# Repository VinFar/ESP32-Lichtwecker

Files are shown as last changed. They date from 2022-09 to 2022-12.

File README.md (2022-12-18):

ESP32 Lichtwäcker
===
# Introduction
This repository is about a custom built alarm clock, which wakes you up with light instead of sound. It mimics the sunrise inside your bedroom, so that you are been woken up gently and more natural. The main light source (a.k.a. wake light) is a high power LED with around 50W of power. This is plenty of power to illuminate a big room.

It features a convient Web Interface, where you configure the alarm clock.
You can set the alarm time, the rising time, the maximum LED power and much more.
When a alarm sets in, the brightness is slowly increased (configurable) until the maximum power (configurable) is reached. Then the brightness is held at this point for specific amount of time (configurable).

With the integrated button it is possible to switch off the alarm, activate a "reading light" (low brightness), activate full power or activate the last use RGB Effect.

Beside the high power LED there are 24 WS2812B RGB LED chips arranged in a circle. This makes it possible to use the alarm clock also as a mood or RGB light. It features a lot of effects, that can be selected over the Web Interface.

# Features
The alarm clock has the following features:

- **50W high power LED**
- **High efficient LED driver**
- **ESP32 to control everythin**
- **Custom PCB which implements the electronics**
- **RGB LEDs to create beautiful animations and mood lights**
- **Web Interface to configure the following settings**
  - **Alarm time for each day of the week**
  - **Brightness rising and holding time**
  - **LED power for the wake light**
  - **RGB effect for the mood light**
- **OTA Updates**
- **Alexa and Google Assistant ready ("Alexa, set the alarm light to 20%")**
- **Temperature sensor for the high power LED**
- **Aluminium heat sink with a 30mm fan for cooling**
  - **Fan can switched off, as it obviously makes noise, which is not necessarily desirable when you wake up :)**
- **All parts (beside LED heatsink) are 3D-printable**

## Main LED
___
The mainlight source is a high quality power LED from CREE (CMT2850). It features a CRI of 92, a natural color of 5000K and around 50W of power. It is mounted to the heatsink.
It is driven by an LCM-60 CC-Source from Meanwell. This LED driver has a maximum power output of 60W and can drive a current of max. 1400mA.
For dimming the LED a PWM signal from the ESP32 is used. It is coupled to via an opto-coupler, to prevent GND shifts and other interferences.

## ESP32
___
The alarm clock is powered and controlled over a ESP32. It is mounted on the PCB.

## Other features
___
### Temperature sensor
A LM335 temperature sensor is fixed to the bottom of the heatsink to measure the temperature of the of the main LED. The LM335 outputs an analog voltage which is then measured by an ADC. This method was used over a classic digital OneWire sensor, as the I²C Library is immune to context switches of FreeRTOS. Also, id prevents using a fake DS18B20, as these are very common on AliExpress, eBay etc.

### Fan & heat managment
To enable better cooling of the alarm clock a 30mm fan is used. It is controlled a PWM single, to reduce noise when the temperature is not too hot. In addition, it can completely switched off over the Web Interface.
In both cases a heat managment controls the power of the LED and the fan. The power of the LED is continously reduced, if the the temperature is higher than 70°C.
Thus, the fan can be switched off, resulting in a lower brightness of the LED.

### 

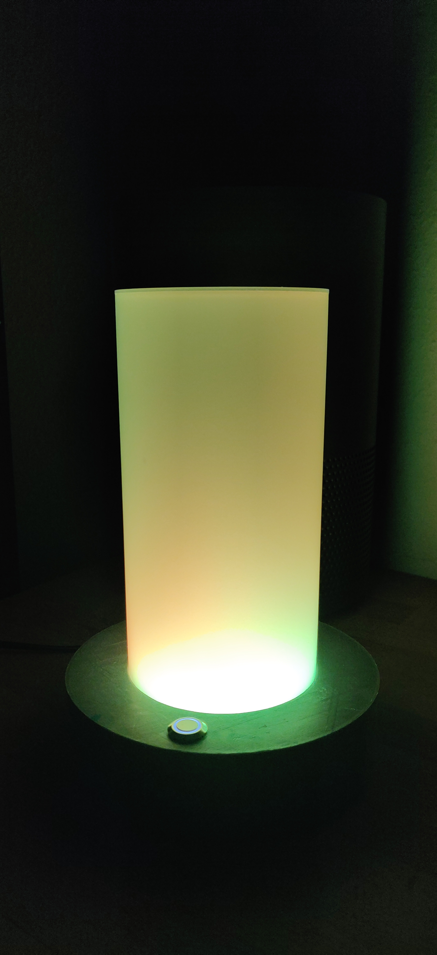
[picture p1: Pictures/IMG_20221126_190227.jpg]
[](image.png)
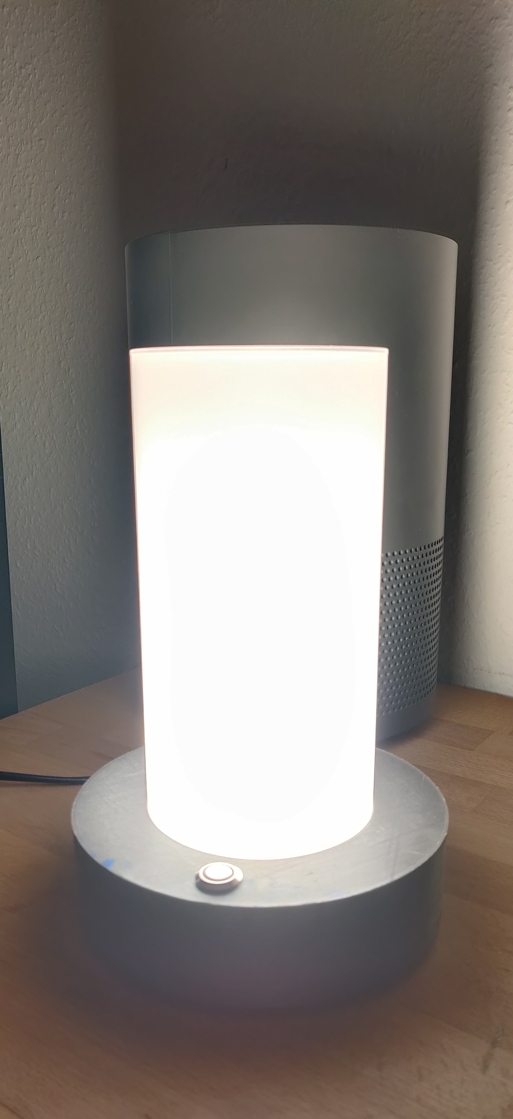
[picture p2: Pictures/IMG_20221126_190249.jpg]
[](image.png)

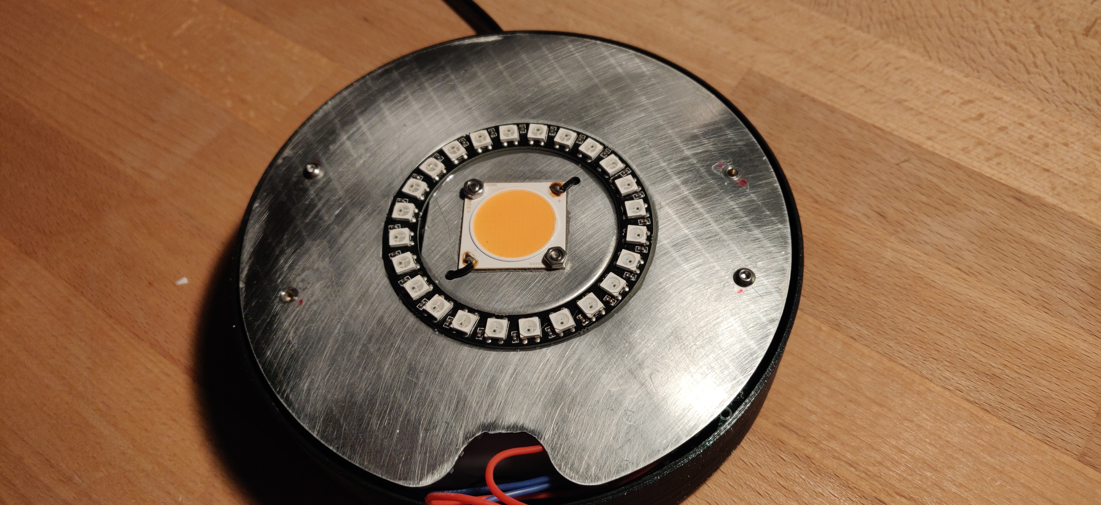
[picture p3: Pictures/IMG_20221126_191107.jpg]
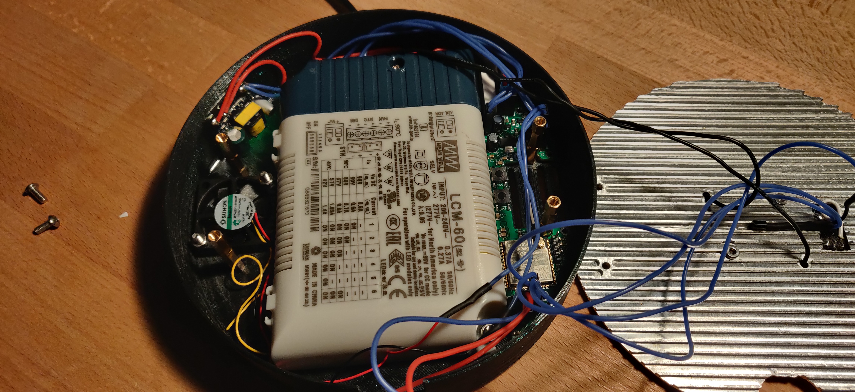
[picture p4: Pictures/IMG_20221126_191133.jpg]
[](image.png)[](image.png)

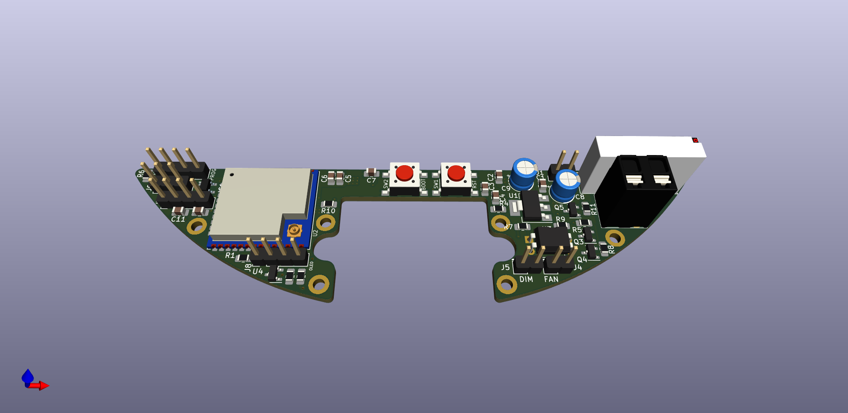
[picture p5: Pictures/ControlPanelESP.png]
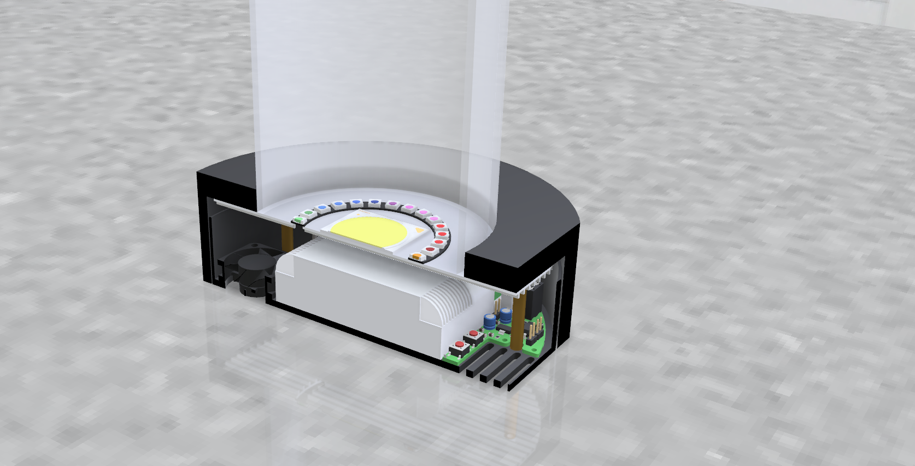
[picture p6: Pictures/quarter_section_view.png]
[](image.png)[](image.png)

### Hardware

### Firmware

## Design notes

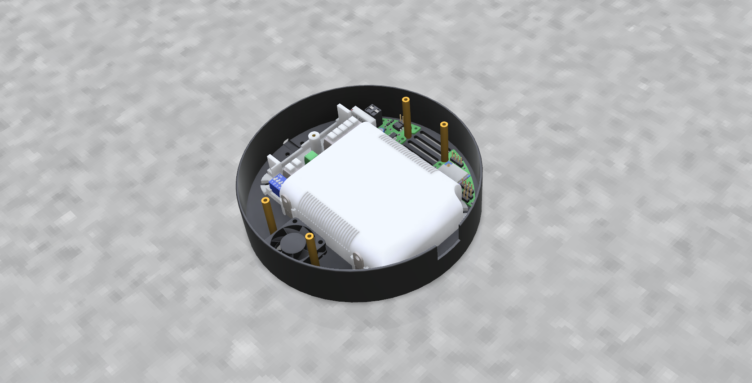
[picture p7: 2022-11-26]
Pictures/electronics1.png

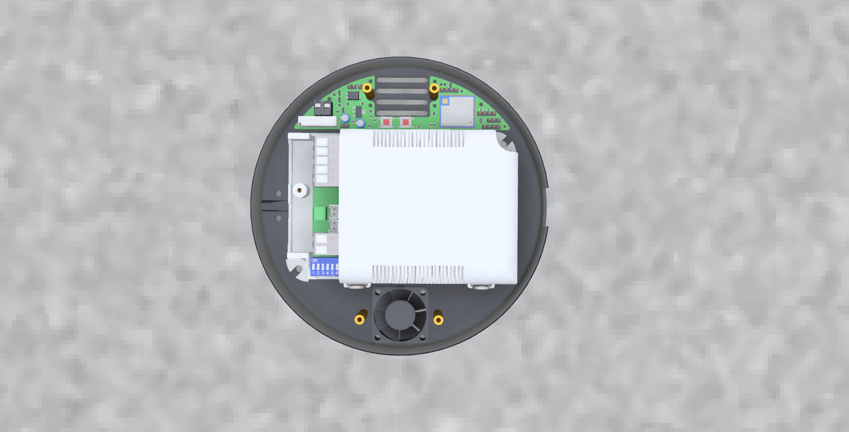
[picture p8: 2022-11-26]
Pictures/electronics2.png

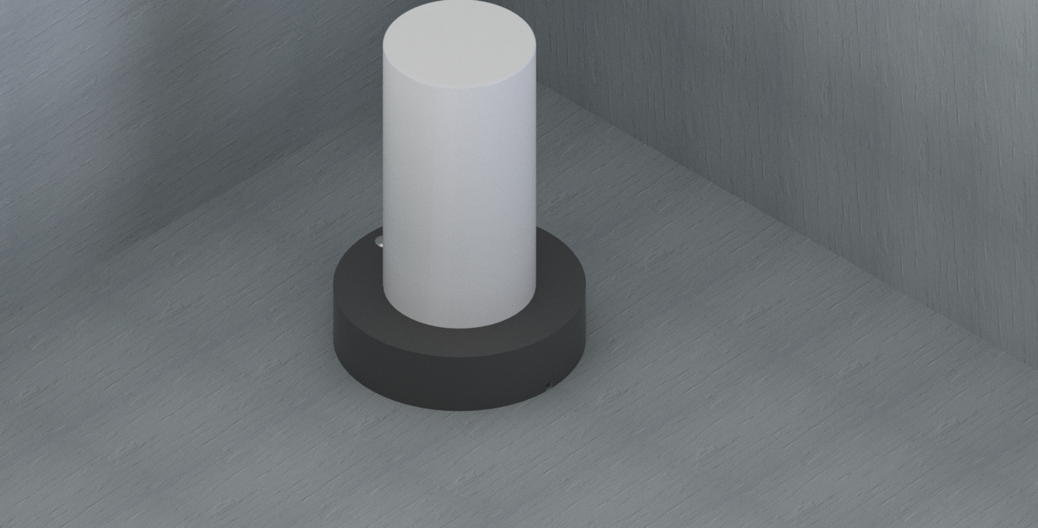
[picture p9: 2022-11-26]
Pictures/assembyl_fuß.png

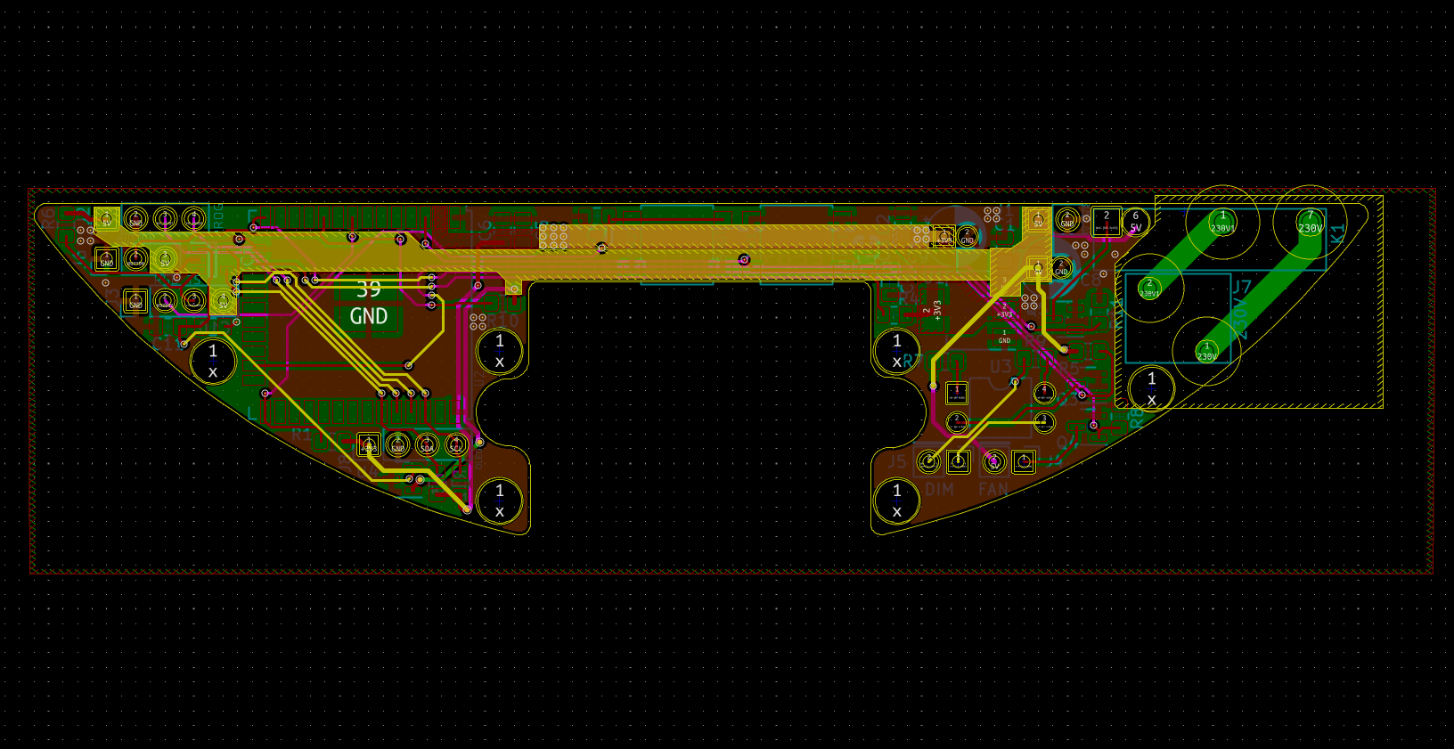
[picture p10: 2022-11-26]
Pictures/Layout.png

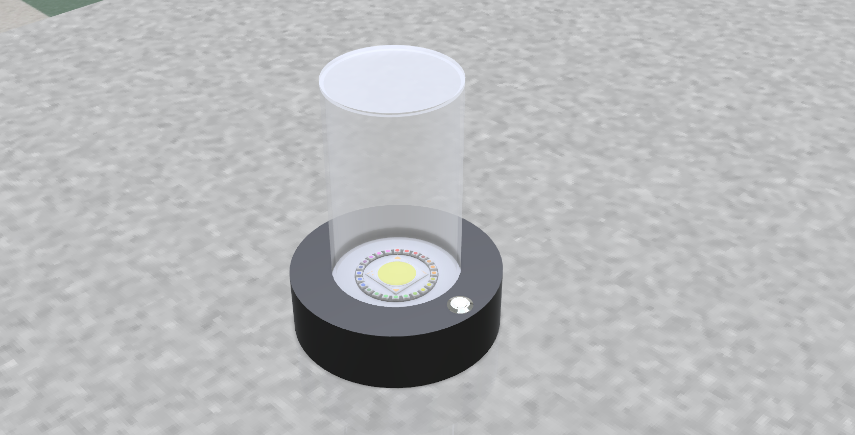
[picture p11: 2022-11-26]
Pictures/assemlbed.png

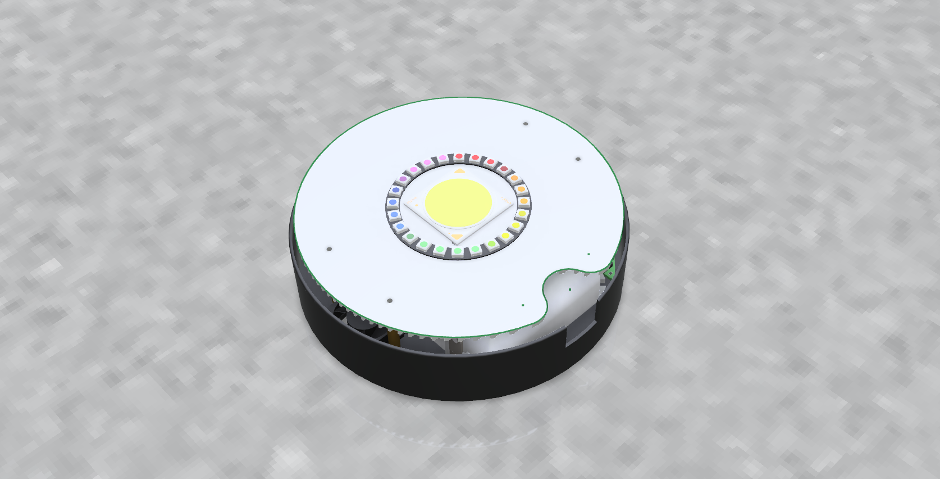
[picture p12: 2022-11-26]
Pictures/aluminium_plate.png

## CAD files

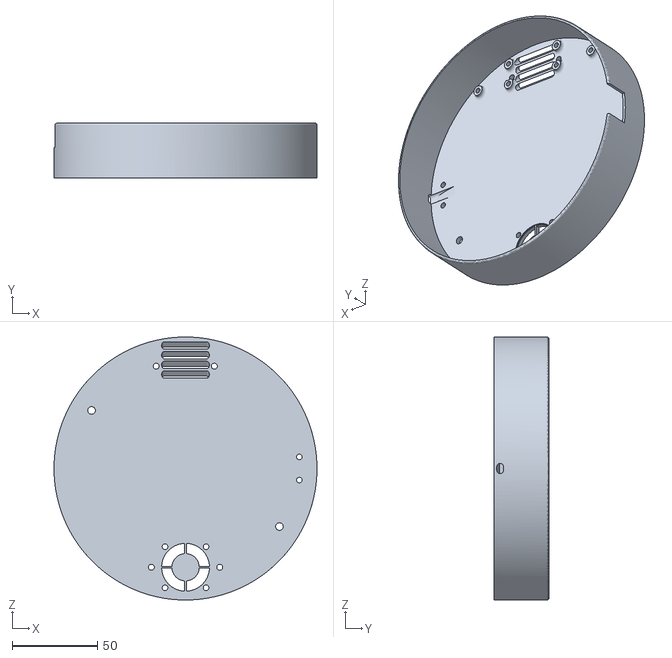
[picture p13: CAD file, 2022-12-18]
3D-Models/Schale.stl
154.0 x 32.0 x 154.0

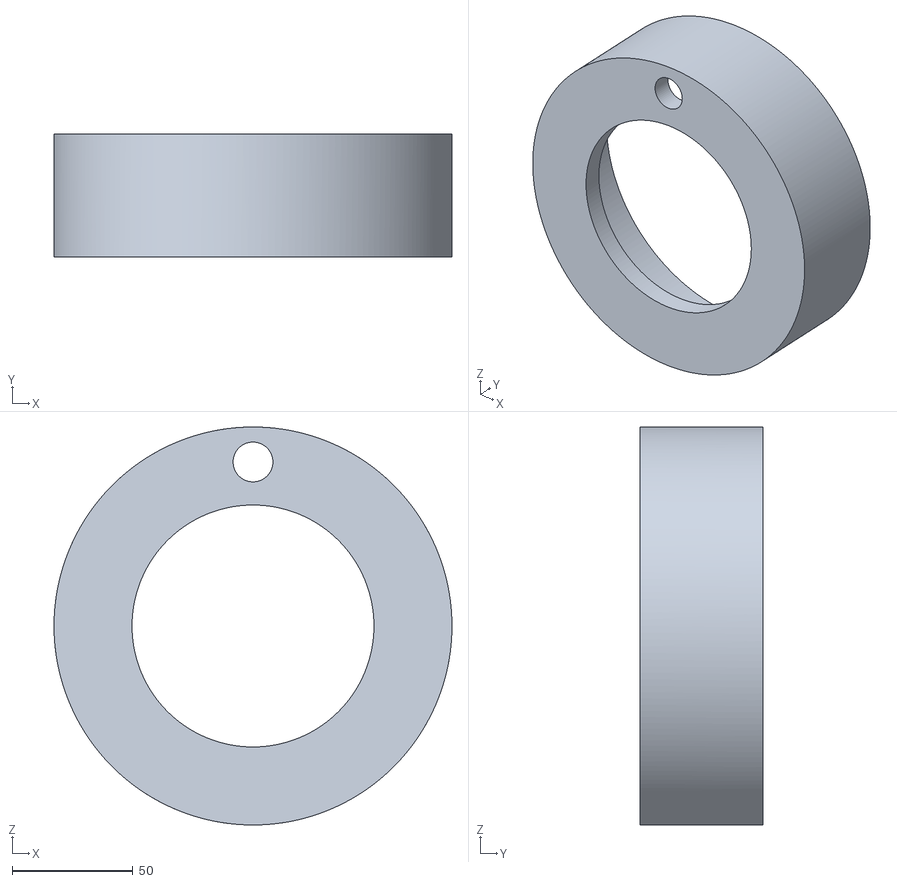
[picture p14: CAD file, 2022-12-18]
3D-Models/Oberteil.stl
165.0 x 51.0 x 165.0

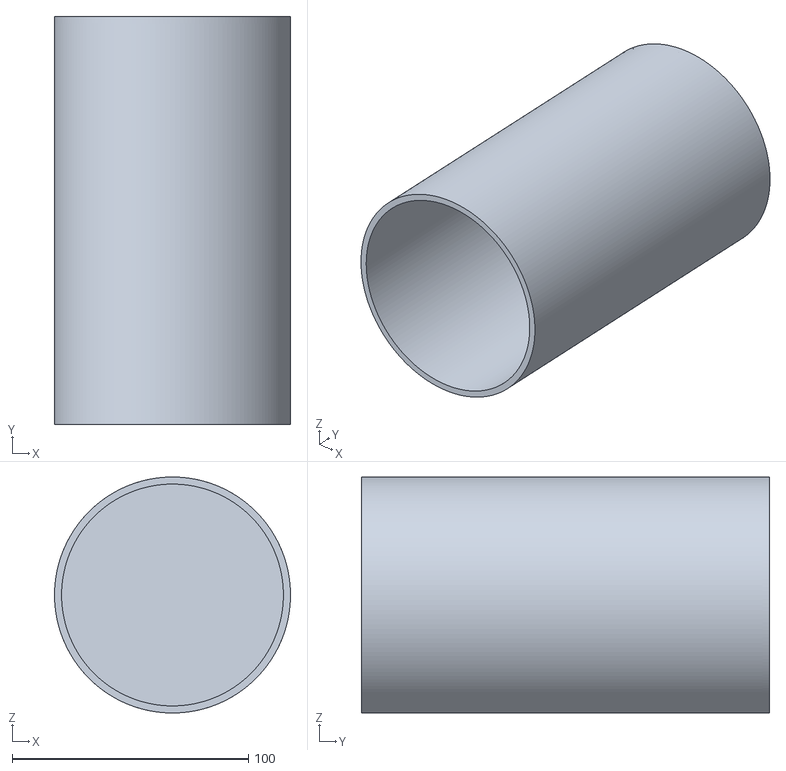
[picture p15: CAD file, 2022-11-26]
3D-Models/Plexiglas.stl
100.0 x 173.0 x 100.0

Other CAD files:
KiCad/ControlPanelESP/ControlPanelESP.iam
KiCad/ControlPanelESP/HF49FDxxx-1Hx2x.iam
KiCad/ControlPanelESP/SOLID.ipt

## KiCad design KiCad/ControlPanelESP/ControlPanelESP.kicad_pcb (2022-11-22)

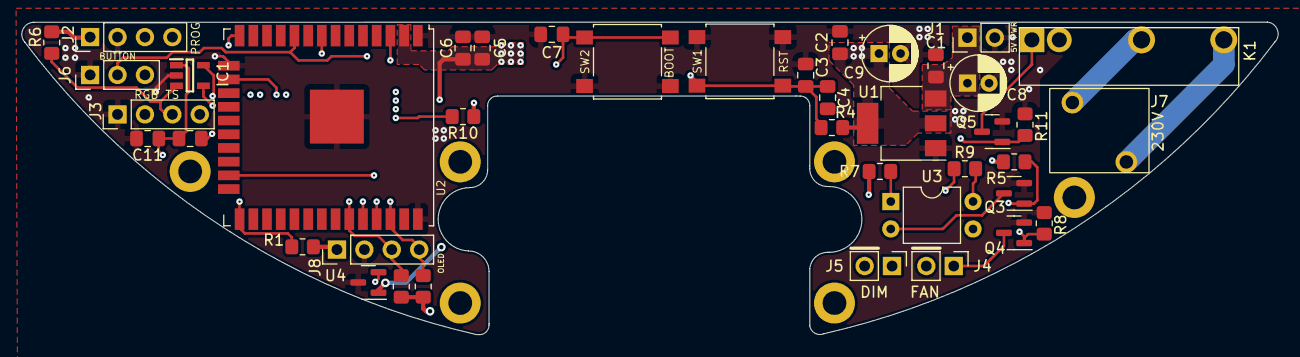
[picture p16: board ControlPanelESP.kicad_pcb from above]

Board: 4 copper layers, 116.4 x 29.0 mm, 47 parts (0 on the bottom side), 25 nets.

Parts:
C1, C2, C5: 22u; C_0805_2012Metric_Pad1.18x1.45mm_HandSolder
C3, C4, C6, C7, C11: 100n; C_0805_2012Metric_Pad1.18x1.45mm_HandSolder
C8, C9: C_Polarized; CP_Radial_D5.0mm_P2.00mm
C10: 10u; C_0805_2012Metric_Pad1.18x1.45mm_HandSolder
H1, H2, H3, H4, H5, H6: MountingHole_Pad; MountingHole_2.2mm_M2_DIN965_Pad
IC1: MCP3221A6T-E_OT; SOT95P280X145-5N
J1, J4, J5: Conn_01x02_Male; PinHeader_1x02_P2.54mm_Vertical
J2, J3, J8: Conn_01x04_Male; PinHeader_1x04_P2.54mm_Vertical
J6: Conn_01x03_Male; PinHeader_1x03_P2.54mm_Vertical
J7: 2086-3122
K1: DIPxx-1Axx-11x; HF49FD-005-1H
Q3, Q4, Q5: Q_NMOS_GSD; SOT-23
R1, R4, R5, R8, R10, R11: 10k; R_0805_2012Metric_Pad1.20x1.40mm_HandSolder
R3, R12: 4k7; R_0805_2012Metric_Pad1.20x1.40mm_HandSolder
R6: 5.1k; R_0805_2012Metric_Pad1.20x1.40mm_HandSolder
R7, R9: 1k; R_0805_2012Metric_Pad1.20x1.40mm_HandSolder
SW1, SW2: SW_Push; SW_SPST_B3S-1000
U1: AMS1117-3.3; SOT-223-3_TabPin2
U2: ESP32-WROOM-32U
U3: LTV-817; DIP-4_W7.62mm
U4: MCP1541-TT; SOT-23

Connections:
5V: C1.1, C8.1, J1.1, J2.1, J3.4, J4.2, J6.3, K1.6, R5.1, R6.1, R7.1, R10.1, U1.3 (VI), U4.1 (Vin)
+3V3: C2.1, C5.2, C6.2, C9.1, J8.1, R1.1, R3.1, R4.1, R12.1, U1.2 (VO), U2.2 (VDD)
/230V: J7.1, K1.7
/230V1: J7.2, K1.1
BUTTON: J6.2, R10.2, U2.10 (IO25)
EN: C3.1, C4.2, R4.2, SW1.2, U2.3 (EN)
FAN: Q4.1 (G), R8.1, U2.14 (IO12)
GND: C1.2, C2.2, C3.2, C4.1, C5.1, C6.1, C7.2, C8.2, C9.2, C10.2, C11.2, IC1.2 (VSS), J1.2, J2.2, J3.1, J6.1, J8.2, Q3.2 (S), Q4.2 (S), Q5.2 (S), R8.2, R11.2, SW1.1, SW2.2, U1.1 (GND), U2.1 (GND), U2.15 (GND), U2.38 (GND), U2.39 (GND), U4.3 (Vss)
IO0: C7.1, R1.2, SW2.1, U2.25 (IO0)
LED: Q3.1 (G), R5.2, U2.16 (IO13)
unnamed: C10.1, C11.1, IC1.1 (VDD), U4.2 (Vout)
unnamed: J4.1, Q4.3 (D)
unnamed: J5.1, U3.3
unnamed: J5.2, R9.2
unnamed: K1.2, Q5.3 (D)
unnamed: Q3.3 (D), U3.2
unnamed: R7.2, U3.1
unnamed: R9.1, U3.4
RX_ESP32: J2.3, U2.34 (RXD0/IO3)
Relay: Q5.1 (G), R11.1, U2.23 (IO15)
SCL: IC1.5 (SCL), J8.4, R12.2, U2.36 (IO22)
SDA: IC1.4 (SDA), J8.3, R3.2, U2.33 (IO21)
TEMPSENSOR: IC1.3 (AIN), J3.3, R6.2
TX_ESP32: J2.4, U2.35 (TXD0/IO1)
WS2812: J3.2, U2.8 (IO32)

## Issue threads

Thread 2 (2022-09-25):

Add DS2482 OneWire to I²C Chip for easier temperature read-out

VinFar, 2022-09-25:
Currently the Temperatur Sensor is directly connected to the ESP32 via OneWire. This leads to problems in the software and FreeRTOS. Can be avoided by using the IC DS2482

VinFar, 2022-11-24:
obsolete, as Temperature is measured over LM335 + ADC

Closed 2022-11-24.

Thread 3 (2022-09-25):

Add missing socket for Button and Neopixel JST connector

VinFar, 2022-09-25:
The current KiCad layout does not contain the JST XH sockets for the NeoPixel LEDs and the Button. Must be implemented into the new version.

VinFar, 2022-11-24:
fixed in 5a814dc04d3ae7fad7bdb4948d1ecee875b64b8e

Closed 2022-11-24.

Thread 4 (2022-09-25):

Add Pull Up on GPIO0 for correct reset of ESP32

VinFar, 2022-09-25:

VinFar, 2022-11-24:
fixed in 5a814dc04d3ae7fad7bdb4948d1ecee875b64b8e

Closed 2022-11-24.

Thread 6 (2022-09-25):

Increase thickness of aluminium heatsink for High power LED

VinFar, 2022-09-25:
The current aluminium heatsink for the High Power LED (aka Wake LED) is very thin (3mm). Thus, it does not have a lot of heat capacity to absorb the heat energy of the LED.

If the heatsink has more heat capacity the fan of the Lichtwecker will be switched on later. This decreases the amount of noise the Lichtwecker produces

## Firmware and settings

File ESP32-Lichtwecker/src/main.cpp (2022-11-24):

#include <Arduino.h>
#include "Debug.h"
#include "Preferences.h"
#include "myWifi.h"
#include "myRTC.h"
#include "myLED.h"
#include "ESPUI.h"
#include "AlarmTask.h"
#include "TemperatureSensor.h"
#include "WebServerUI.h"
#include "Button.h"
#include "NeoPixel.h"
#include "SinricSmart.h"
#include "OTA.h"

#define DEBUG_MSG DEBUG_MSG_MAIN

float Test = 1.324f;

void setup()
{
  Serial.begin(1000000);
  NeoPixelInit();
  LedWakeInit();
  LedWakeSetDutyCycle(0);
  LedWakeFanSetDutyCycle(100.0f);
  TempSensorInit();
  ButtonInit();
  AlarmTaskInitPrefs();
  
  xTaskCreatePinnedToCore(TaskWifi,"TaskWifi",4000,NULL,1,NULL,CONFIG_ARDUINO_RUNNING_CORE);

  // ESPUI.prepareFileSystem();
}

void loop()
{
  ButtonTick();
  NeoPixelTick();
  //SinricHandle();
  OtaTick();
  TempSensorTick();
}

#undef DEBUG_MSG

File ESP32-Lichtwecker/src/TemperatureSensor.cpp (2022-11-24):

#include "main.h"
#include "TemperatureSensor.h"
#include "ESPUI.h"
#include "WebServerStatusTab.h"
#include "myLED.h"
#include "WebServerUI.h"
#include "NeoPixel.h"
#include <Wire.h>
#include "mcp3221.h"

#define DEBUG_MSG DEBUG_MSG_TEMP

MCP3221 mcp3221(ADC_I2C_ADDRESS);
const uint8_t address = ADC_I2C_ADDRESS;
const uint16_t ref_voltage = 4086;  // in mV

TimerHandle_t TempSensorWatchDogTimer=NULL;

void TaskTemperature(void *arg);
static float TemperatureCalcMaxPWM(float Temp);
static float TemperatureCalcFanPower(float Temp);
static void TempSensorOkCallback();
static void TempSensorNotOkCallback();
void TempSensorWatchDogExpiredCallback(TimerHandle_t TimerID);
void TemperatureSensorRead();

float CurrentTemp;
String TemperatureString = "-20.00";
int TempSensorOk=false;

void TempSensorInit()
{
    Wire.begin(SDA, SCL);
    mcp3221.init(20, 60);

    uint16_t result = mcp3221.readMean();
    float voltage = mcp3221.toVoltage(result, ref_voltage);
    DEBUG_PRINT("ADC counts: %d" CLI_NL, result);
    DEBUG_PRINT("ADC Voltage: %d" CLI_NL, voltage);

    xTaskCreatePinnedToCore(TaskTemperature, "TaskTemperature", 8000, NULL, 4, NULL, CONFIG_ARDUINO_RUNNING_CORE);
    TempSensorWatchDogTimer = xTimerCreate("TempSensorWatchdog",pdMS_TO_TICKS(5000),pdTRUE,(void*)0,TempSensorWatchDogExpiredCallback);
    if(TempSensorWatchDogTimer != NULL){
        xTimerStart(TempSensorWatchDogTimer,pdMS_TO_TICKS(100));
    }else{
        DEBUG_PRINT("Could not create TempSensorWatchdog Timer" CLI_NL);
        TempSensorOk=false;
    }
}

void TaskTemperature(void *arg)
{
    while(1){
        TemperatureSensorRead();
        vTaskDelay(TASK_TEMPERATURE_TICK);
    }
}

float TemperatureSensorGetTempC(){
    uint16_t result = mcp3221.readMean();

    return (mcp3221.toVoltage(result, ref_voltage) / 10.0f) - 273.15f;
}

void TemperatureSensorRead(){

    CurrentTemp = TemperatureSensorGetTempC();
    if (CurrentTemp != TEMP_ERROR)
    {
        //DEBUG_PRINT("Temperature: %3.2f°C" CLI_NL, CurrentTemp);
        TemperatureString = String(CurrentTemp, 2);
        if (WebUiIsStarted())
        {
            ESPUI.print(WebUiGetTemperatureLabelId(), TemperatureString);
        }
        float MaxPwm = TemperatureCalcMaxPWM(CurrentTemp);
        float FanPwm = TemperatureCalcFanPower(CurrentTemp);
        LedWakeFanSetDutyCycle(FanPwm);
        LedPwmMaxSet(MaxPwm);
        TempSensorOk=true;
        if(TempSensorWatchDogTimer != NULL){
            xTimerReset(TempSensorWatchDogTimer,pdMS_TO_TICKS(100));
        }
    }else{
        DEBUG_PRINT("Could not read Temp Sensor. Resetting oneWire." CLI_NL);
    }
}

int TempSensorStatus(){
    return TempSensorOk;
}

void TempSensorWatchDogExpiredCallback(TimerHandle_t TimerID){
    DEBUG_PRINT("Watchdog of TempSensor expired" CLI_NL);
    TempSensorNotOkCallback();
}

static void TempSensorNotOkCallback(){
    DEBUG_PRINT("Error on Temperature Sensor" CLI_NL);
    LedWakeSetDutyCycle(0.0f);
    NeoPixelShowStatusError();
    TempSensorOk=false;
}

static void TempSensorOkCallback(){
    DEBUG_PRINT("Temperature Sensor OK" CLI_NL);
    TempSensorOk=true;
}

void TempSensorTick()
{
    mcp3221.tick();
}


/*
 * This function calculates the maximum pwm for the LED for a given temp
 * Above 80.0°C the maximum pwm decreases with 10% per 1°C, so that the
 * maximum temp is somewhere between 80°C and 90°C.
 */
static float TemperatureCalcMaxPWM(float Temp)
{
    if (Temp > 90.0f)
        return 0.0f;
    if (Temp < 0.0f)
        return 50.0f;
    if (!TempSensorStatus())
        return 0.0f;

    float pwm;

    pwm = -10 * Temp + 800;

    if (pwm > 100.0f)
        return 100.0f;
    if (pwm < 0.0f)
        return 0.0f;
    DEBUG_PRINT("Limiting Max PWM to %.2f. Current Temperature: %.2f°C" CLI_NL, pwm, Temp);
    return pwm;
}

static float TemperatureCalcFanPower(float Temp)
{

    float pwm = 3.333 * Temp - 166.666;

    if (pwm < 0)
        pwm = 0.0f;
    if (pwm > 100.0f)
        pwm = 100.0f;

    return pwm;
}

#undef DEBUG_MSG

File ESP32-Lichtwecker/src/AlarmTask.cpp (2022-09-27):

#include "AlarmTask.h"
#include <Preferences.h>
#include "main.h"
#include "Debug.h"
#include "myRTC.h"
#include "myLED.h"
#include "NeoPixel.h"

#define DEBUG_MSG DEBUG_MSG_ALARMS

Preferences prefs;
const char *AlarmPrefsNameSpace = "Alarm";
const char *AlarmPrefAlarmStatus = "AlarmStatus";
const char *AlarmPrefsLedPowerOffTimer = "LedPowerOff";
TaskHandle_t TaskAlarmTriggeredTaskHandle = NULL;
bool AlarmStatusAll = true;
TaskHandle_t TaskAlarmTaskHandle = NULL;

int AlarmCheckForAlarmTrigger(struct tm CurrentTime, int *AlarmIndex);
static void TaskAlarmTriggered(void *arg);
static void AlarmTaskReadStruct(Alarm_t *AlarmPtr, size_t size);
static int AlarmTaskReadLedPowerOffTimer();
static bool AlarmTaskReadAlarmStatusAll();

Alarm_t Alarms[7] = {{Monday, "Montags"}, {Tuesday, "Dienstag"}, {Wednesday, "Mittwoch"}, {Thursday, "Donnerstag"}, {Friday, "Freitag"}, {Saturday, "Samstag"}, {Sunday, "Sonntag"}};
int AlarmIndexes[7];

int AlarmLedOffTimerValue;

void AlarmTaskInitPrefs()
{
    AlarmTaskReadStruct(Alarms, sizeof(Alarms));

    AlarmLedOffTimerValue = AlarmTaskReadLedPowerOffTimer();
    AlarmStatusAll = AlarmTaskReadAlarmStatusAll();
}

void TaskAlarm(void *arg)
{
    DEBUG_PRINT("Created Task for Alarm Checking" CLI_NL);
    TaskAlarmTaskHandle = xTaskGetCurrentTaskHandle();
    int AlarmToTrigger;
    struct tm CurrentRtcTime;
    int AlarmIndex;
    while (1)
    {
        RtcGetCurrentTime(&CurrentRtcTime);
        if (AlarmStateGet())
        {
            AlarmToTrigger = AlarmCheckForAlarmTrigger(CurrentRtcTime, &AlarmIndex);
            if (AlarmToTrigger == 1)
            {
                if (TaskAlarmTriggeredTaskHandle == NULL)
                {
                    DEBUG_PRINT("Alarm for %s triggered. Starting Task..." CLI_NL, Alarms[AlarmIndex].WeekDayString);
                    AlarmIndexes[AlarmIndex] = AlarmIndex;
                    xTaskCreatePinnedToCore(TaskAlarmTriggered, "TaskAlarmTriggered", 4000, &AlarmIndexes[AlarmIndex], 1, NULL, CONFIG_ARDUINO_RUNNING_CORE);
                }
                else
                {
                    DEBUG_PRINT("Alarm triggered but another alarms is already running" CLI_NL);
                }
            }
            vTaskDelay(pdMS_TO_TICKS(59000));
        }
        else
        {
            DEBUG_PRINT("Alarm Status is set off. Suspending TaskAlarm" CLI_NL);
            vTaskSuspend(NULL);
            DEBUG_PRINT("TaskAlarm resumed" CLI_NL);
        }
    }
}

TaskHandle_t TaskAlarmGetTaskHandle()
{
    return TaskAlarmTaskHandle;
}

static void TaskAlarmTriggered(void *arg)
{
    uint32_t IndexOfAlarmStruct = (uint32_t) * ((uint32_t *)arg);
    float CurrentPwm = 1.0f;
    float MaximumPwm = Alarms[IndexOfAlarmStruct].AlarmMaxLight;
    uint32_t EndTicks = xTaskGetTickCount() + pdMS_TO_TICKS(Alarms[IndexOfAlarmStruct].AlarmDuration * 60 * 1000);
    float PwmToIncreasePerStep;
    if(Alarms[IndexOfAlarmStruct].AlarmDuration==0.0f){
        PwmToIncreasePerStep=100.0f;
        CurrentPwm=100.0f;
    }else{
        PwmToIncreasePerStep = MaximumPwm / (Alarms[IndexOfAlarmStruct].AlarmDuration * 60);
    }

    DEBUG_PRINT("Task started for triggering alarm. Index: %d | Max Power: %d | DC/s: %.4f P/s" CLI_NL, IndexOfAlarmStruct, MaximumPwm, PwmToIncreasePerStep);
    TaskAlarmTriggeredTaskHandle = xTaskGetCurrentTaskHandle();
    while (1)
    {
        LedWakeSetDutyCycle(CurrentPwm);
        CurrentPwm += PwmToIncreasePerStep;
        vTaskDelay(pdMS_TO_TICKS(1000));
        if (xTaskGetTickCount() > EndTicks)
        {
            break;
        }
        DEBUG_PRINT("PWM set to %.4f" CLI_NL, CurrentPwm);
    }
    DEBUG_PRINT("Finished with Rising LED Power. Powering LED for %d mins" CLI_NL, AlarmLedOffTimerGet());
    vTaskDelay(pdMS_TO_TICKS(AlarmLedOffTimerGet() * 60 * 1000));
    LedWakeSetDutyCycle(0.0f);
    DEBUG_PRINT("Alarm is finished! Deleting Task..." CLI_NL);
    TaskAlarmTriggeredTaskHandle = NULL;
    vTaskDelete(NULL);
}

int8_t ButtonSingleClickAlarmCallback()
{
    if (TaskAlarmTriggeredTaskHandle != NULL)
    {
        vTaskDelete(TaskAlarmTriggeredTaskHandle);
        TaskAlarmTriggeredTaskHandle = NULL;
        LedWakeSetDutyCycle(0.0f);
        DEBUG_PRINT("Button was pressed while Alarm was running. Aborted the Alarm" CLI_NL);
        return 1;
    }
    return 0;
}

/*
 * Sunday is 0 in tm struct
 */
int AlarmCheckForAlarmTrigger(struct tm CurrentTime, int *AlarmIndex)
{
    DEBUG_PRINT("Checking if Alarm needs to be triggered. Current Time: %02d:%02d" CLI_NL, CurrentTime.tm_hour, CurrentTime.tm_min);
    for (int i = 0; i < ARRAY_LEN(Alarms); i++)
    {
        if (Alarms[i].WeekDay == CurrentTime.tm_wday)
        {
            DEBUG_PRINT("WDay OK" CLI_NL);
            if (Alarms[i].Hour == CurrentTime.tm_hour)
            {
                DEBUG_PRINT("Hours OK" CLI_NL);
                if (Alarms[i].Minute == CurrentTime.tm_min)
                {
                    DEBUG_PRINT("Minutes OK" CLI_NL);
                    if (Alarms[i].AlarmOnOff)
                    {
                        DEBUG_PRINT("Triggered Alarm %s at %02d:%02d" CLI_NL, Alarms[i].WeekDayString, Alarms[i].Hour, Alarms[i].Minute);
                        *AlarmIndex = i;
                        return 1;
                    }
                }
            }
        }
    }
    *AlarmIndex = -1;
    return 0;
}

void AlarmStatusSet(bool NewState)
{
    AlarmStatusAll = NewState;
}

bool AlarmStateGet()
{
    return AlarmStatusAll;
}

bool *AlarmStatusGetAddress()
{
    return &AlarmStatusAll;
}

int8_t AlarmStatusSaveToNvs()
{
    if (!prefs.begin(AlarmPrefAlarmStatus, false))
    {
        DEBUG_PRINT("Could not open NameSpace" CLI_NL);
        NeoPixelShowStatusError();
        return -1;
    }
    if (!prefs.putBytes(AlarmPrefAlarmStatus, &AlarmStatusAll, sizeof(AlarmStatusAll)))
    {
        DEBUG_PRINT("Could not write Namespace %s" CLI_NL, AlarmStatusAll);
        NeoPixelShowStatusError();
        return -1;
    }
    prefs.end();
    DEBUG_PRINT("Wrote Alarm Status to NVS" CLI_NL);
    return 0;
}

void AlarmSetLedPower(uint8_t Index, float DC)
{
    Alarms[Index].AlarmMaxLight = DC;
}

void AlarmSetTimeInterval(uint8_t Index, uint32_t Time)
{
    if(Time > 60)
        Time = 60;
    Alarms[Index].AlarmDuration = Time;
}

void AlarmSetLedOffTimer(int NewValue)
{
    DEBUG_PRINT("LED Power Off Timer set to %d" CLI_NL, NewValue);
    AlarmLedOffTimerValue = NewValue;
}

int AlarmLedOffTimerGet()
{
    return AlarmLedOffTimerValue;
}

void AlarmLedOffTimerSaveToNVS()
{
    prefs.begin(AlarmPrefsLedPowerOffTimer);
    // prefs.putInt(AlarmPrefsLedPowerOffTimer, AlarmLedOffTimerValue);
    prefs.end();
    NeoPixelBlinkForFeedback(0,255,0);

    DEBUG_PRINT("LED Power Off Timer saved to NVs" CLI_NL);
}
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

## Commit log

2021-12-11 add: print SSID and IP Address when connected to WiFi
2021-12-11 add: PWM for WakeLight and Fan
2021-12-17 add: kicad project
    [ESP32-Lichtwecker.kicad_pcb, ESP32-Lichtwecker.sch]
2021-12-18 add: Tabs for all Weekdays, Dynamic switching on/off of Alarms for each weekday
2021-12-20 add: Function for setting Switcher State, set Switcher to correct state at init
2021-12-25 add: Save button for Wake Time, Read Wake Time from NVS on Reset
2021-12-28 working Alarm Trigger, Global On/Off Switch
2021-12-28 add: Function to set Power for LED Wake light
2021-12-28 add: TemperatureSensor, TemperaturTask
2021-12-28 add: Temperature report in Status Tab
2021-12-29 add: PWM Limit for LED depending on Temp of LED
2021-12-29 re activated Reset of LED PWM afters setting pwm level for Wake Light
2021-12-29 offset for PWM of 11 and lower slope to reach 100%
2021-12-29 add: Set correct saved value to GUI for time interval and led power
2021-12-31 fixed wrong LED Power Label
    [WebServerStatusTab.cpp, myLED.cpp]
2021-12-31 add: LED Power Off Timer after Wake Rising
2021-12-31 add: Debug print statement when saving Alarms struct to NVS
2022-01-02 add: PWM for FAN
2022-01-02 add: Button
2022-01-02 Abort Alarm with Button Single Click
2022-01-02 add: Button Clock for Reading Light On/Off
2022-01-02 add: increase/decrease LED Read light with long button press
2022-01-08 fixed code for warning
    [AlarmTask.cpp]
2022-01-08 removed print statement
2022-01-09 removed Debug print statement
2022-01-10 deactivate RGB Effect with Button Click
2022-01-30 removed old KiCad project
    [ESP32-Lichtwecker.kicad_pcb, ESP32-Lichtwecker.sch]
2022-01-30 first version of schematic
    [ControlPanelESP.kicad_pcb, ControlPanelESP.kicad_sch]
2022-01-31 added symbol for relay
2022-02-03 add: gitignore for Kicad
2022-02-03 removed kicad file from tracking
2022-02-03 initial version of PCB
    [ControlPanelESP.kicad_pcb, ControlPanelESP.kicad_sch]
2022-09-13 second version
    [ControlPanelESP-B_Cu.gbl, ControlPanelESP-B_Mask.gbs, ControlPanelESP-B_Paste.gbp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]
2022-09-13 error check on AlarmRisingTime Set
    [AlarmTask.cpp]
2022-09-13 set NeoPixel off when Reading Light is switched off
2022-09-14 add: OTA Update Prototype
2022-09-14 add: exception decoder to monitor filter of pio
2022-09-14 add: Booting and Error Status over NeoPixel, Feedback over NeoPixel when usin WebUI
    [AlarmTask.cpp, Button.cpp, OTA.cpp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]
2022-09-14 fix: Reading Light PWM value was too low
    [myLED.cpp]
2022-09-14 ch: do not discard PWM increase interval of 0
2022-09-14 add: report current led brightness back to Sinric
2022-09-24 ch: better debug print statements for LED Power Slider
2022-09-24 add: Debug print statement when maximum power of LED was reduced due to too high temp of led
    [myLED.cpp]
2022-09-24 add: debug print statements for Temp sensor
2022-09-24 ch: request temperature to end of loop right before TaskDelay
2022-09-26 add: oneWire reset and delay before init of DS18B20
    [TemperatureSensor.cpp]
2022-09-26 add: Temperature Sensor Tick for implementation in loop()
2022-09-26 add: FreeRTOS Timer as Watchdog for Temp Sensor, reset oneWire when expired, do not set Wake LED on Temp Sensor Error
    [TemperatureSensor.cpp, TemperatureSensor.h, myLED.cpp]
2022-09-26 working watchdog for temp sensor
2022-09-26 add: double click for 100% Power, triple click for ESP Reset
    [Button.cpp]
2022-09-26 TempSensor not working due to fake DS18B20
    [TemperatureSensor.cpp]
2022-09-26 add: correct formatting for DutyCycle value
    [myLED.cpp]
2022-09-26 add: prototypes for CLI
2022-09-26 fix: forgot to increment array size of Debug Prefixes
    [Debug.h]
2022-09-30 fix: removed extra Readout of Temp Sensor over loop()
    [main.cpp]
2022-10-08 V2.0 of PCB
    [ControlPanelESP.kicad_pcb, ControlPanelESP.kicad_sch]
2022-10-09 finalized PCB
    [ControlPanelESP.kicad_pcb, ControlPanelESP.kicad_sch]
2022-10-09 finalized PCB again
    [ControlPanelESP.kicad_pcb]
2022-10-09 add: OLED Display Connector, some markers
    [ControlPanelESP.kicad_pcb, ControlPanelESP.kicad_sch]
2022-10-09 add: OLED Display Header
    [ControlPanelESP.kicad_sch]
2022-10-23 ch: MCP1541 as voltage reference for ADC
    [ControlPanelESP-B_Cu.gbl, ControlPanelESP-B_Mask.gbs, ControlPanelESP-B_Paste.gbp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]
2022-11-23 add: Temperature Sensor with LM335 and ADC
2022-11-23 add: MeanBuffer for ADC
2022-11-23 working Temp Sensor with ADC and LM335
2022-11-23 add: Relay ON/OFF for LED CC Source
2022-11-26 add: 3D Models
    [ControlPanelESP.step, Oberteil.stl, Plexiglas.stl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]
2022-11-26 updated 3D Model for lower part
    [Schale.stl]
2022-12-18 add: kicad lockfile to gitignore
2022-12-18 changed 3D Models for upper and lower part
    [Oberteil.stl, Schale.stl]
